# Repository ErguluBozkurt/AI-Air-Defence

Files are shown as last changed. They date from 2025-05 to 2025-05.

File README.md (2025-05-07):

# 🚀 Otonom Hava Savunma Sistemi (Raspberry Pi 4B + YOLOv8)
*Mavi balon tespiti ve otomatik takip sistemi*

Bu proje, Raspberry Pi kullanılarak mavi renkli nesnelerin gerçek zamanlı olarak tespit edilmesi, step motor ile nesneye yönelme, nesneye ulaşıldığında servo motor ve DC motorlarla silah sisteminin devreye girmesi ile atış gerçekleştirilmesini sağlayan **görsel tabanlı bir otomasyon sistemidir**. YOLOv8 modeli ile görüntü üzerinde nesne tespiti yapılmakta ve buna göre donanım bileşenleri eş zamanlı olarak kontrol edilmektedir.

---

## 📌 Proje Amacı

- **Görüntü İşleme**: Raspberry Pi üzerinde çalışan kamera ile gerçek zamanlı görüntü yakalanması.
- **Yapay Zeka**: YOLOv8 nesne tespiti algoritmasıyla mavi renkteki nesnelerin algılanması.
- **Hareket Mekaniği**: Step motorlarla kameranın nesneye yönelmesi.
- **Tepki Mekanizması**: Servo motorun nesne merkezdeyken çalışması.
- **Hareket Komutu**: Nesne algılandıktan sonra atış için DC motorların belirli süre çalıştırılması.

---

## 🧠 Algoritma Akışı

1. PiCamera2 aracılığıyla görüntü alınır.
2. YOLOv8 modeli ile her kare üzerinde nesne tespiti yapılır.
3. Eğer "mavi nesne" tespit edilirse:
   - Nesnenin konumu çerçeve ortasına göre analiz edilir.
   - Gerekirse step motorlar ile yön düzeltmesi yapılır.
4. Nesne merkezdeyse:
   - DC motorlar çalıştırılır.
   - Servo motor çalıştırılır.
6. Eğer nesne tespit edilmezse, sistem bekleme moduna geçer.

---

## 🧰 Donanım Gereksinimleri

| Bileşen | Açıklama |
|---|---|
| Raspberry Pi 4 | Ana kontrol birimi |
| Raspberrypi Kamera | Görüntü alma işlemini gerçekleştirir |
| 2 Adet Step Motor | Kamera sisteminin X-Y düzleminde yönelmesini sağlar |
| 1 Adet Servo Motor | Hedef merkezdeyken tetiklenir |
| 2 Adet DC Motor | Tespit sonrası belirli süre hareket eder |
| L298N Motor Sürücü | DC motorları kontrol etmek için kullanılır |
| Jumper Kabloları | Bağlantılar için |
| Harici Güç Kaynağı | DC motorlar için önerilir |

---

## 🔌 GPIO Pin Bağlantı Şeması

| Bileşen | GPIO Pinleri | Açıklama |
|---|---|---|
| Step Motor X | GPIO 5, 6, 13, 26 | X ekseninde yönelme |
| Step Motor Y | GPIO 1, 7, 8, 12 | Y ekseninde yönelme |
| Servo Motor | GPIO 16 | Hedef merkezdeyse çalışır |
| DC Motor 1/2 | GPIO 17, 22, 23, 24, 25, 27 | L298N sürücü ile yön kontrolü |

---

## 🖥️ Yazılım Gereksinimleri

- Python 3.x (>=3.7)
- `OpenCV` — Görüntü işleme
- `ultralytics` — YOLOv8 modeli için
- `picamera2` — Raspberry Pi kamerası desteği
- `RPi.GPIO` — GPIO pin kontrolü
- `numpy` — Görüntü matris işlemleri

---

## ⚙️ Kurulum Adımları

1. Raspberry Pi işletim sisteminizi güncelleyin:
   ```bash
   sudo apt update && sudo apt upgrade
   sudo apt install python3-pip
   pip install -r requirements.txt

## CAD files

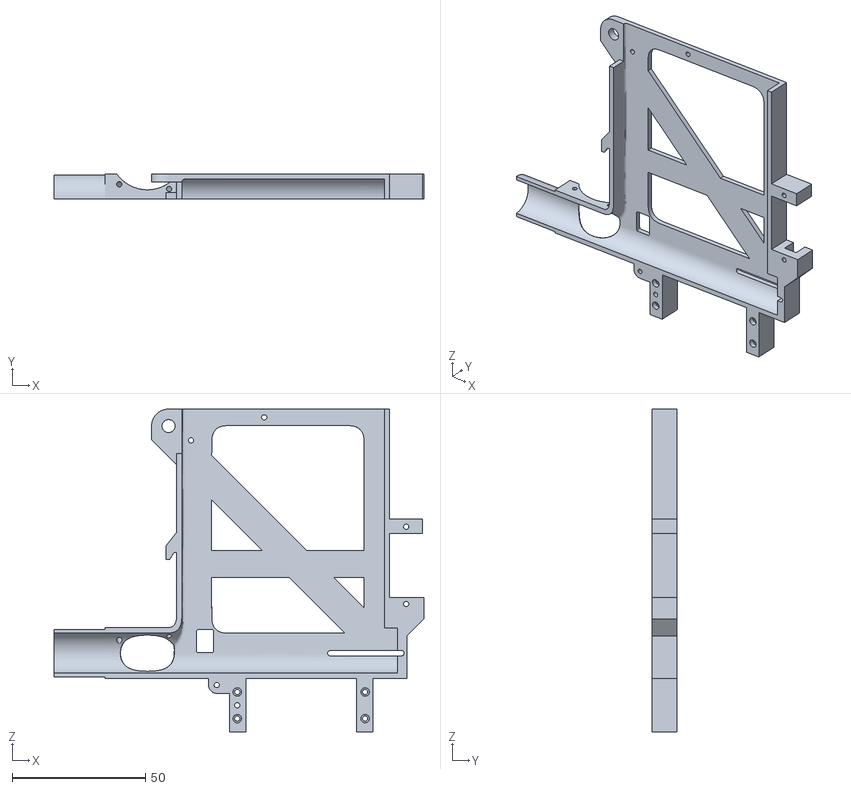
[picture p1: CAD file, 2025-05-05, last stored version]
tasarım/ANA R.stl
138.9 x 9.51 x 121.2

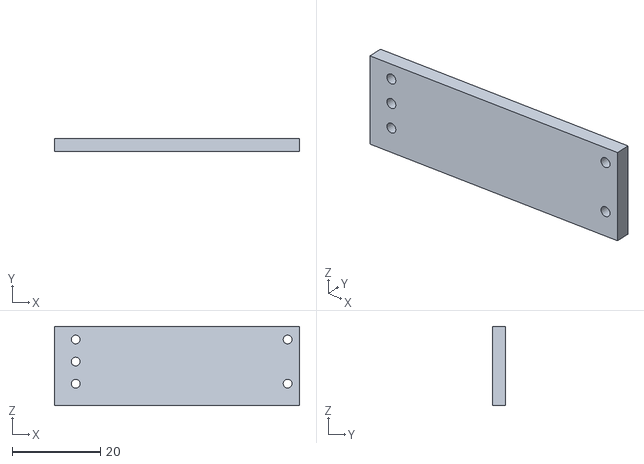
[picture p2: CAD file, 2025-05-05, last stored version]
tasarım/SERVO L.stl
55.5 x 3.00 x 18.0

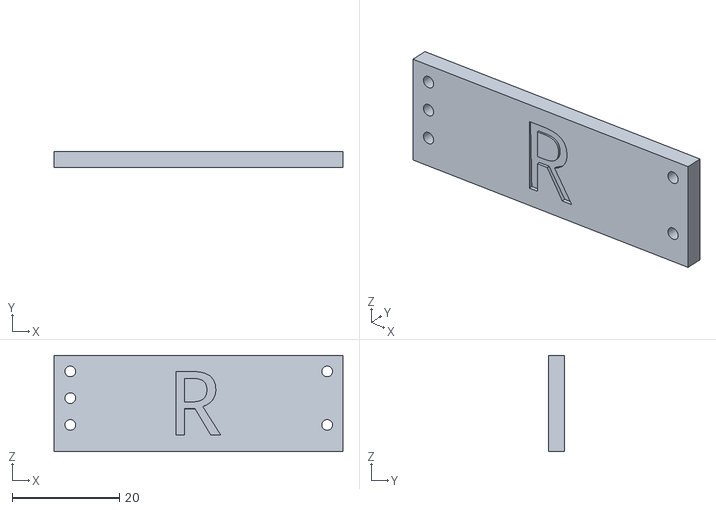
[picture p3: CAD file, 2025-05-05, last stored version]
tasarım/SERVO R.stl
54.0 x 3.00 x 18.0

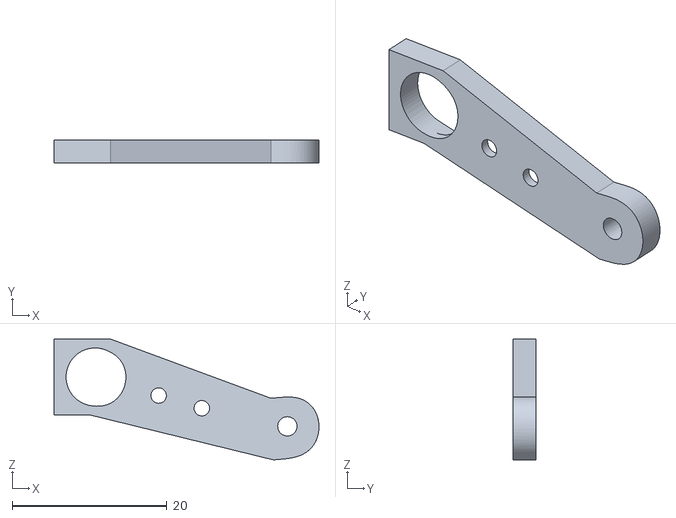
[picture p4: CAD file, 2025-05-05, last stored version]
tasarım/Recoil_arm.stl
34.3 x 2.96 x 15.6

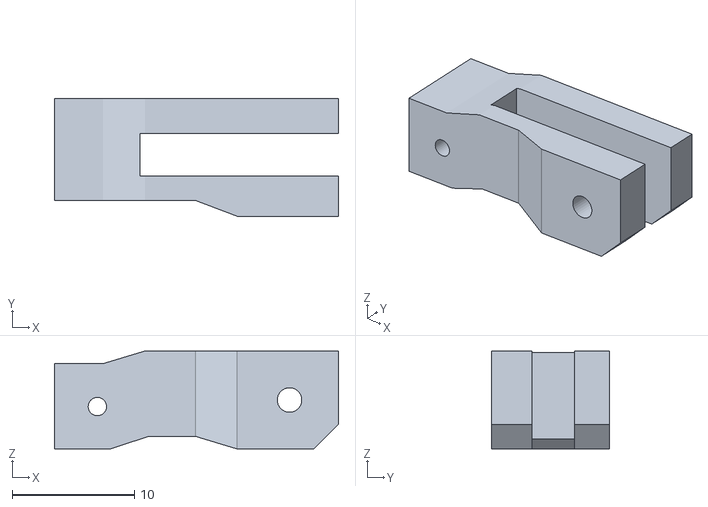
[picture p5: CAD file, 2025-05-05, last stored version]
tasarım/Recoil_arm_2.stl
23.2 x 9.60 x 8.00

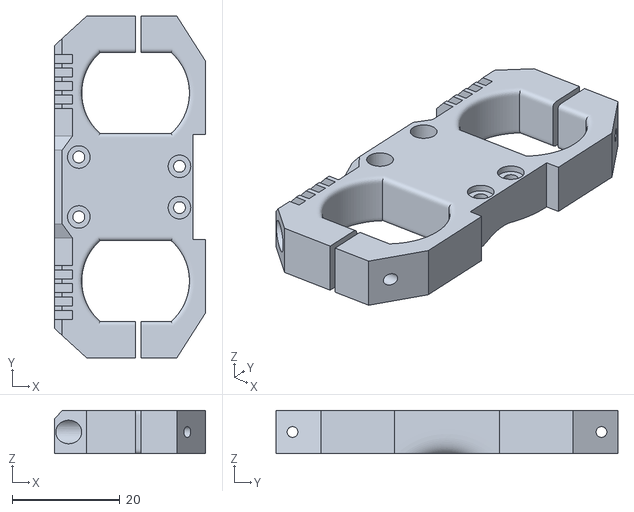
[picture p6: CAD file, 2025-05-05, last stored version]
tasarım/Motor_bracket_3mm.stl
28.1 x 63.6 x 8.00

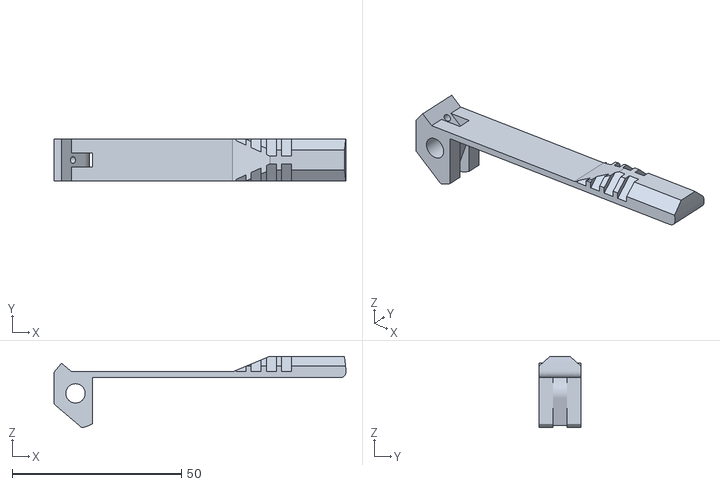
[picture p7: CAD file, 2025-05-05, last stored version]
tasarım/Top_cap.stl
86.3 x 12.4 x 21.1

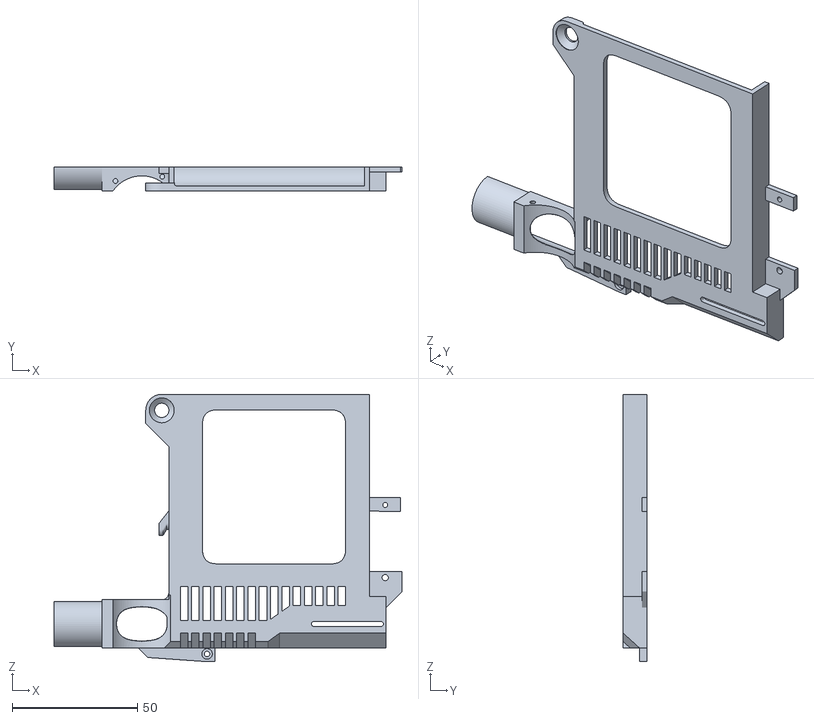
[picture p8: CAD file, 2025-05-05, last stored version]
tasarım/ANA L.stl
138.9 x 9.50 x 106.7

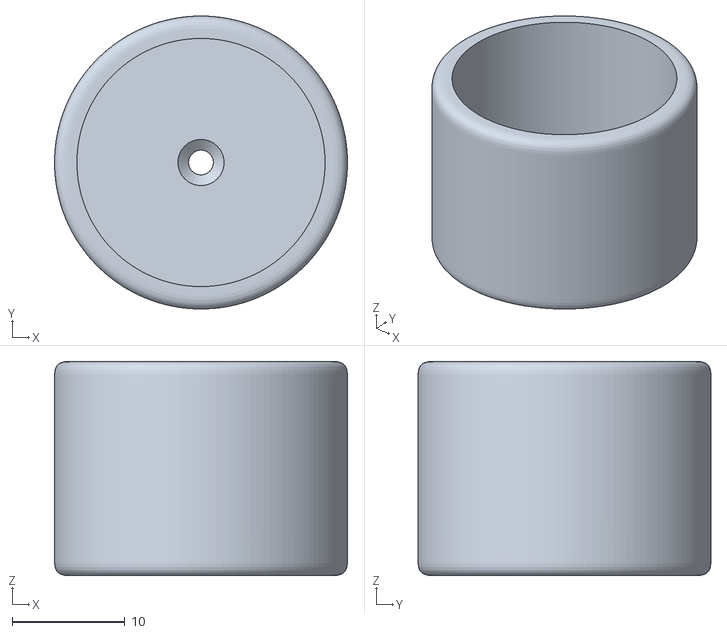
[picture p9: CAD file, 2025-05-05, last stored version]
tasarım/Roller.stl
26.0 x 26.0 x 19.0

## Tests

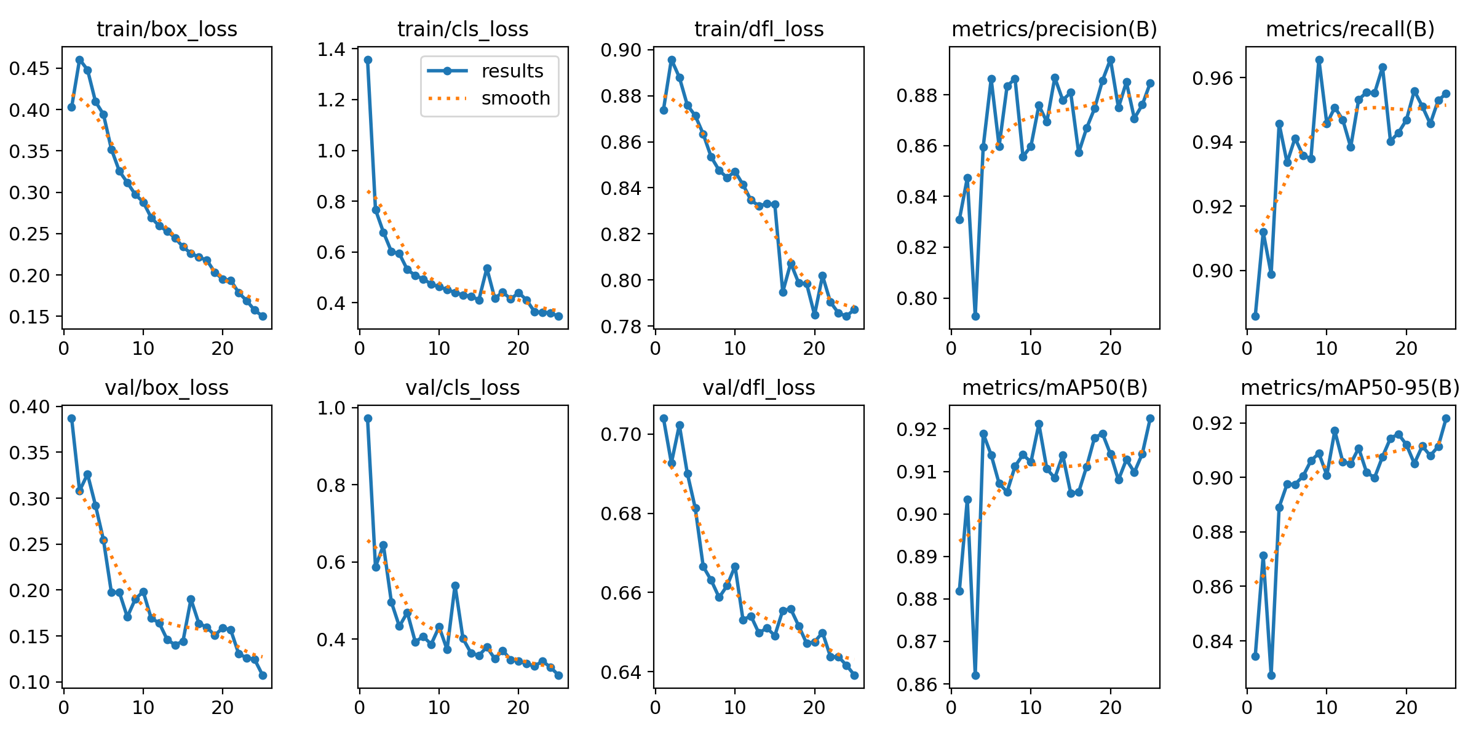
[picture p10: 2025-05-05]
YOLOv8 Mavi Tespiti/results.png

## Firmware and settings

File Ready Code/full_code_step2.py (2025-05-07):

# DC motorlar ve servo eklendi dcmotor.py dosyası ile birlikte çalışıyor. Tüm sistem çalışıyor.

import cv2
import numpy as np
from collections import deque
from picamera2 import Picamera2
import RPi.GPIO as GPIO
import time
from ultralytics import YOLO
import dcmotor  # dcmotor.py modülünü çağırıyoruz


buffer_size = 16
pts = deque(maxlen=buffer_size)

# Initialize camera
picam2 = Picamera2()
picam2.preview_configuration.main.size = (720, 480)
picam2.preview_configuration.main.format = "RGB888"
picam2.preview_configuration.align()
picam2.configure("preview")
picam2.start()

# Load YOLO model trained to detect blue objects
model = YOLO("best.pt")

# GPIO pin setup
gpio_x = [5, 6, 13, 26]
gpio_y = [1, 7, 8, 12]
GPIO.setmode(GPIO.BCM)
GPIO.setup(gpio_x, GPIO.OUT)
GPIO.setup(gpio_y, GPIO.OUT)

# Half-step sequence
step_sequence = [
    [1, 0, 0, 0],
    [1, 1, 0, 0],
    [0, 1, 0, 0],
    [0, 1, 1, 0],
    [0, 0, 1, 0],
    [0, 0, 1, 1],
    [0, 0, 0, 1],
    [1, 0, 0, 1]
]


def step_motor(steps, gpio, direction, delay=0.002):
    for _ in range(int(steps)):
        for step in step_sequence[::direction]:
            GPIO.output(gpio, step)
            time.sleep(delay)

# Servo motor setup with pin 14
SERVO_PIN = 16  # Your new servo signal pin
GPIO.setup(SERVO_PIN, GPIO.OUT)
p_servo = GPIO.PWM(SERVO_PIN, 50)  # 50 Hz frequency
p_servo.start(0)

# Motorları başlat
dcmotor.setup_motors()

# Set servo angle (0–180 degrees)
def set_angle(angle):
    duty_cycle = (angle / 18) + 2  # Convert angle to duty cycle
    p_servo.ChangeDutyCycle(duty_cycle)
    time.sleep(0.3)  # Allow movement
    p_servo.ChangeDutyCycle(0)  # Prevent jitter

# Move to 0°, then 60°
def move_servo():
    set_angle(0)
    set_angle(60)


while True:
    frame = picam2.capture_array()

    results = model(frame)[0]
    center = None

    for result in results.boxes.data.tolist():
        x1, y1, x2, y2, score, class_id = result
        x1, y1, x2, y2, class_id = int(x1), int(y1), int(x2), int(y2), int(class_id)

        if score > 0.2:
            cv2.rectangle(frame, (x1, y1), (x2, y2), (0, 255, 0), 2)
            class_name = results.names[class_id]
            score_percent = round(score * 100, 2)
            text = f"{class_name}:{score_percent}%"
            cv2.putText(frame, text, (x1, y1 - 10), cv2.FONT_HERSHEY_COMPLEX_SMALL, 0.75, (0, 255, 255), 1)

            obj_center_x = (x1 + x2) // 2
            obj_center_y = (y1 + y2) // 2
            center = (obj_center_x, obj_center_y)

            diff_x = 360 - obj_center_x
            diff_y = 240 - obj_center_y

            s = f"x : {obj_center_x} y : {obj_center_y}"
            s1 = f"X-axis stepper motor : {diff_x} Y-axis stepper motor : {diff_y}"
            cv2.circle(frame, center, 5, (255, 0, 255), -1)
            cv2.putText(frame, s, (20, 30), cv2.FONT_HERSHEY_COMPLEX_SMALL, 0.7, (255, 255, 255), 1)
            cv2.putText(frame, s1, (20, 70), cv2.FONT_HERSHEY_COMPLEX_SMALL, 0.7, (255, 255, 255), 1)

            if diff_x > 0:
                STEP_COUNT_X = 2048 / (300 - abs(center[0]))
                step_motor(STEP_COUNT_X, gpio_x, direction=1)
                if diff_y > 0:
                    STEP_COUNT_Y = 2048 / (180 - abs(center[1]))
                    step_motor(STEP_COUNT_Y, gpio_y, direction=-1)
                elif diff_y < 0:
                    STEP_COUNT_Y = 2048 / (180 - abs(center[1]))
                    step_motor(STEP_COUNT_Y, gpio_y, direction=1)

            elif diff_x < 0:
                STEP_COUNT_X = 2048 / (300 - abs(center[0]))
                step_motor(STEP_COUNT_X, gpio_x, direction=-1)
                if diff_y > 0:
                    STEP_COUNT_Y = 2048 / (180 - abs(center[1]))
                    step_motor(STEP_COUNT_Y, gpio_y, direction=-1)
                elif diff_y < 0:
                    STEP_COUNT_Y = 2048 / (180 - abs(center[1]))
                    step_motor(STEP_COUNT_Y, gpio_y, direction=1)

            if abs(abs(diff_x) - center[0]) <= 10 and abs(abs(diff_y) - center[0]) <= 10:
                dcmotor.start_motors(speed=30)
                move_servo()
                dcmotor.stop_motors()
                # Şartlar sağlandığında motorları çalıştır

            else:
                p_servo.stop()
                dcmotor.stop_motors()

    pts.appendleft(center)
    for i in range(1, len(pts)):
        if pts[i - 1] is None or pts[i] is None:
            continue
        cv2.line(frame, pts[i - 1], pts[i], (0, 255, 0), 3)

    cv2.imshow("Image", frame)

    if cv2.waitKey(1) & 0xFF == ord("q"):
        break

# Clean up
GPIO.cleanup()
cv2.destroyAllWindows()
dcmotor.cleanup()

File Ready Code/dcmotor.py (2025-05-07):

# dcmotor.py
import RPi.GPIO as GPIO

# Motor pin tanımlamaları
ENA = 22
INA = 27
INB = 17

ENB = 25
INC = 23
IND = 24

# PWM nesneleri global
p_m1 = None
p_m2 = None

def setup_motors():
    global p_m1, p_m2

    GPIO.setmode(GPIO.BCM)

    GPIO.setup(ENA, GPIO.OUT)
    GPIO.setup(INA, GPIO.OUT)
    GPIO.setup(INB, GPIO.OUT)

    GPIO.setup(ENB, GPIO.OUT)
    GPIO.setup(INC, GPIO.OUT)
    GPIO.setup(IND, GPIO.OUT)

    GPIO.output(INA, GPIO.LOW)
    GPIO.output(INB, GPIO.LOW)
    GPIO.output(INC, GPIO.LOW)
    GPIO.output(IND, GPIO.LOW)

    p_m1 = GPIO.PWM(ENA, 1000)
    p_m1.start(0)

    p_m2 = GPIO.PWM(ENB, 1000)
    p_m2.start(0)

def start_motors(speed=10):
    # Motor 1 ileri
    GPIO.output(INA, GPIO.HIGH)
    GPIO.output(INB, GPIO.LOW)
    p_m1.ChangeDutyCycle(speed)

    # Motor 2 geri
    GPIO.output(INC, GPIO.LOW)
    GPIO.output(IND, GPIO.HIGH)
    p_m2.ChangeDutyCycle(speed)

def stop_motors():
    GPIO.output(INA, GPIO.LOW)
    GPIO.output(INB, GPIO.LOW)
    GPIO.output(INC, GPIO.LOW)
    GPIO.output(IND, GPIO.LOW)
    p_m1.ChangeDutyCycle(0)
    p_m2.ChangeDutyCycle(0)

def cleanup():
    GPIO.cleanup()

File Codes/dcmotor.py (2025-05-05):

# L298N Motor Sürücüsü ile 2 DC Motor Kontrolü ve Servo Motor Kontrolü
import RPi.GPIO as GPIO
import servo

# Motor 1 için pinler (İleri yönde dönecek)
ENA = 22  # Motor 1 Enable
INA = 27  # Motor 1 IN1
INB = 17 # Motor 1 IN2

# Motor 2 için pinler (Geri yönde dönecek)
ENB = 25  # Motor 2 Enable
INC = 23  # Motor 2 IN1
IND = 24  # Motor 2 IN2

# GPIO ayarları
GPIO.setmode(GPIO.BCM)

# Motor 1 için GPIO ayarları
GPIO.setup(ENA, GPIO.OUT)
GPIO.setup(INA, GPIO.OUT)
GPIO.setup(INB, GPIO.OUT)
GPIO.output(INA, GPIO.LOW)
GPIO.output(INB, GPIO.LOW)
p_m1 = GPIO.PWM(ENA, 1000)  # PWM frekansı 1000 Hz
p_m1.start(0)  # Başlangıçta hız %0


# Motor 2 için GPIO ayarları
GPIO.setup(ENB, GPIO.OUT)
GPIO.setup(INC, GPIO.OUT)
GPIO.setup(IND, GPIO.OUT)
GPIO.output(INC, GPIO.LOW)
GPIO.output(IND, GPIO.LOW)
p_m2 = GPIO.PWM(ENB, 1000)  # PWM frekansı 1000 Hz
p_m2.start(0)  # Başlangıçta hız %0

print("\n")
print("Motor kontrol programı başlatıldı.")
print("s - Motorları çalıştır (Motor 1: İleri, Motor 2: Geri) ve Servoyu 60 dereceye döndür")
print("q - Motorları durdur ve Servoyu 0 dereceye döndür")
print("\n")

servo()

while True:
    x = input("Komut girin (start/exit): ")
    if x == 'start':
        print("Motorlar çalıştırılıyor ve Servo 60 dereceye döndürülüyor...")
        # Motor 1: İleri yönde
        GPIO.output(INA, GPIO.HIGH)
        GPIO.output(INB, GPIO.LOW)
        p_m1.ChangeDutyCycle(10)  # %50 hızda çalıştır
        # Motor 2: Geri yönde
        GPIO.output(INC, GPIO.LOW)
        GPIO.output(IND, GPIO.HIGH)
        p_m2.ChangeDutyCycle(10)  # %50 hızda çalıştır

        print("Motor 1: İleri, Motor 2: Geri, Servo: 60 derece")

    elif x == 'exit':
        print("Motorlar durduruluyor ve Servo 0 dereceye döndürülüyor...")
        # Her iki motoru durdur
        GPIO.output(INA, GPIO.LOW)
        GPIO.output(INB, GPIO.LOW)
        GPIO.output(INC, GPIO.LOW)
        GPIO.output(IND, GPIO.LOW)
        p_m1.ChangeDutyCycle(0)  # Hızı %0 yap
        p_m2.ChangeDutyCycle(0)  # Hızı %0 yap

        # Servo motoru 0 dereceye döndür
        set_servo_angle(0)

        print("Motorlar durduruldu ve Servo 0 dereceye döndürüldü.")
        break
    else:
        print("Geçersiz komut! Lütfen 's' veya 'q' girin.")

# Program sonlandığında GPIO temizleme
GPIO.cleanup()

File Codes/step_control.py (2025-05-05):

import RPi.GPIO as GPIO
import time
import dcmotor

# Setup for stepper motors
# GPIO pinlerini tanımla
A = 17
B = 27
C = 22
D = 18

# GPIO modunu belirle
GPIO.setmode(GPIO.BCM)
GPIO.setup([A, B, C, D], GPIO.OUT)

# Half-step sürüş dizisi
step_sequence = [
    [1, 0, 0, 0],
    [1, 1, 0, 0],
    [0, 1, 0, 0],
    [0, 1, 1, 0],
    [0, 0, 1, 0],
    [0, 0, 1, 1],
    [0, 0, 0, 1],
    [1, 0, 0, 1]
]

# 90 derece dönmesi için gereken adım sayısı (Varsayılan: 2048 adım tam tur için)
STEP_COUNT_X = int(2048 / 4)  # 516 = 90 derece için çeyrek tur.
STEP_COUNT_Y = int(2048 / 4)

def step_motor(steps, direction=1, delay=0.002):
    """Step motoru belirtilen adım sayısı kadar döndürür."""
    for _ in range(steps):
        for step in step_sequence[::direction]:  # İleri veya geri yönde git
            GPIO.output([A, B, C, D], step)
            time.sleep(delay)

try:
    print("Step motor 90 derece sağa dönüyor...")
    step_motor(STEP_COUNT_X, direction=1)  # Saat yönünde 90 derece döndür
    
    time.sleep(3) 
    dcmotor()
    print("Step motor eski konumuna dönüyor...")
    step_motor(STEP_COUNT_Y, direction=-1)  # Saat yönünün tersine geri döndür
    time.sleep(3) 
finally:
    GPIO.cleanup()  # GPIO pinlerini temizle
